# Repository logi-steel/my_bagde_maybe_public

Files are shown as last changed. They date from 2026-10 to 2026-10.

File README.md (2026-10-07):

# my_bagde_maybe_public
some ai slop mixed with my learning lol 

# E-ink badge you can reprogram from your phone
**Some ai slop mixed with my learning so pls be carefull.**
A tiny name badge: ESP32-C3 + 2.13" e-paper, **MicroPython**, everything on the screen is described
by one `config.json`. Long-press the button, scan the QR code on the badge, and edit the layout,
add pages, upload images/fonts or even **change the Python code from your phone's browser**. No
PC, no toolchain, no recompiling.

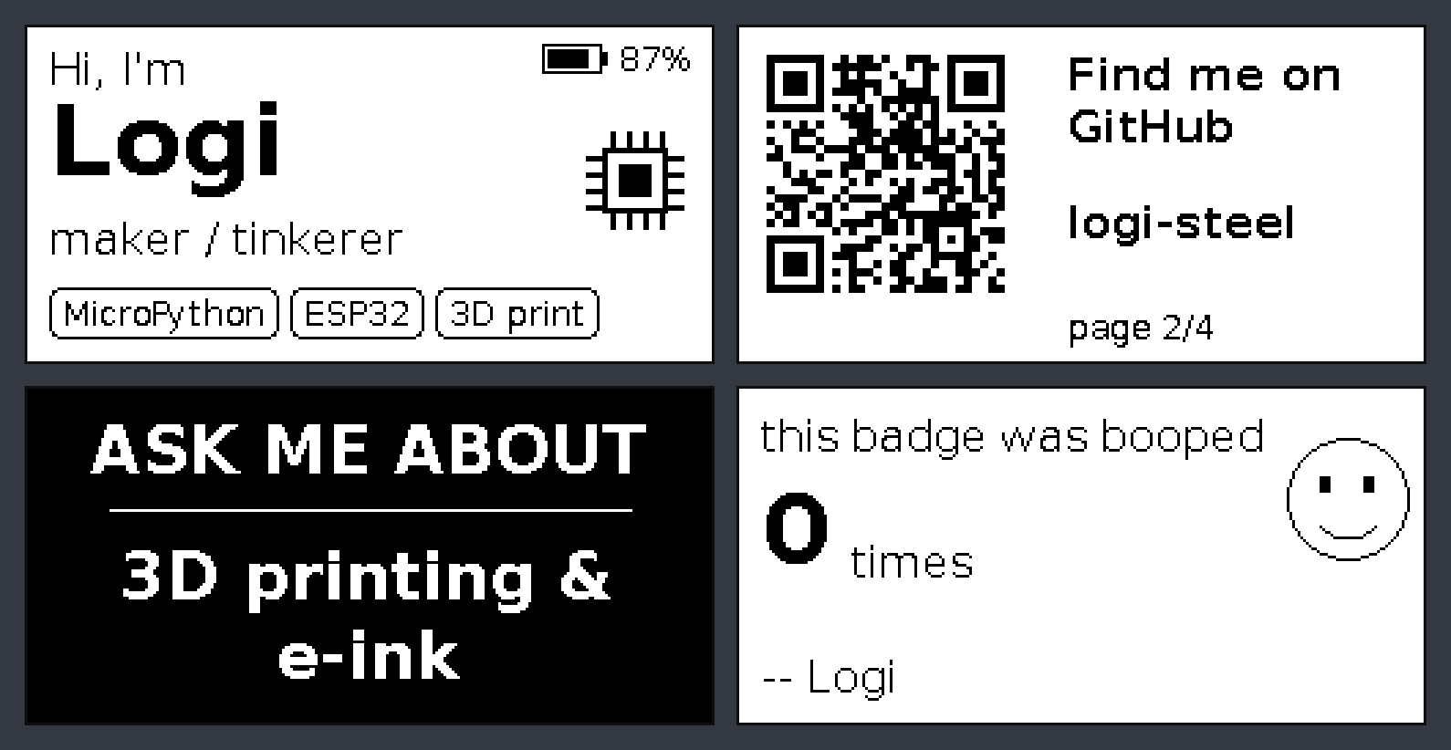
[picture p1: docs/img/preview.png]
preview of the four demo pages


*The picture above is rendered by the badge's own renderer running on a PC (`tools/preview.py`).*

* 250x122 e-paper, always readable, **zero power while showing a page** (deep sleep between presses)
* pages: text (Polish letters included), chips/tags, rectangles, lines, images (a full-screen picture from Canva & co,
  or pixel art typed as text), **QR codes** (generated on the
  device, so a vCard or link can be edited from the phone), battery gauge, and your own **Python plugins**
* Wi-Fi portal with live preview rendered *by the badge itself*, JSON editor, file manager, image
  converter (dithering in the browser), rollback buttons, captive-portal pop-up
* safe by design: configs are validated and `.py` files are compile-checked **before** they are written,
  the previous version is kept as `.bak`, a crashing widget draws a "!" instead of killing the page,
  and if a firmware upload breaks the startup the badge **rolls back to the `.bak` files by itself** (once,
  no ping-pong loops) and keeps the broken version as `.bak` so you can look at it
* 3D-printable case (OpenSCAD, parametric, interference-checked)

## Make your own graphics

> **Use this template to make your own badge graphics!** *(Dzięki temu szablonowi możesz robić własną grafikę!)*

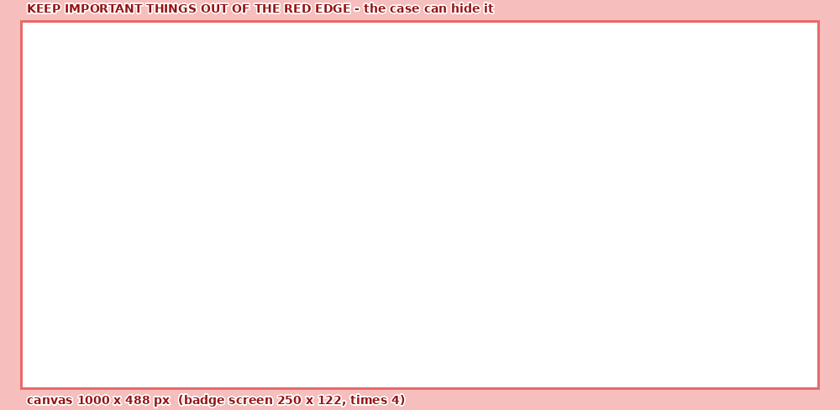
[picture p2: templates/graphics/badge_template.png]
the badge template: a red edge, everything else is yours


Take [`badge_template_overlay.png`](templates/graphics/badge_template_overlay.png) into Canva (or any editor), make a page of
**1000 x 488 px**, lay the overlay over it, draw whatever you like (your cat, any text, anywhere) and delete the overlay
before exporting. Then **Image -> Full screen -> Upload & add as a page** in the badge's portal. The only limits are the
screen size and the red edge the case may hide - [how it works, with an example](templates/graphics/README.md).

> **Read "What is verified and what is not" below before you buy parts or print the case.**
> I had no physical hardware: everything was tested against simulators/mocks and datasheets.

---

## Why MicroPython and not C++?

You all maybe asking whether C++ could update JSON *and code* on the fly. Honest answer:

| | C++ (Arduino/ESP-IDF) | MicroPython |
|---|---|---|
| JSON edited at runtime | easy (ArduinoJson + LittleFS + web server) | easy (`json` is built in) |
| **code changed at runtime** | only as a full firmware OTA: compile on a PC, upload a `.bin`. "Hot" code means embedding an interpreter - i.e. rebuilding MicroPython, worse | **native**: the `.py` files *are* the program, upload one over Wi-Fi and it runs next boot |
| speed | 10-100x faster | irrelevant here: drawing a page takes milliseconds, the e-paper refresh takes seconds |
| RAM/flash | tiny | ~100 KB heap is enough; the C3 has 400 KB SRAM and 4 MB flash |
| battery | slightly better | the badge sleeps at ~uA between presses either way |

C++ would only win for fast animations on a colour TFT. For an e-ink badge it is a bad trade.
**Verdict: MicroPython.** (And I would not choose a colour screen: it needs a backlight and lasts hours,
not weeks.)

---

## Hardware

| Part | What / why | Source of the numbers |
|---|---|---|
| **Seeed XIAO ESP32-C3** | 21 x 17.8 mm, USB-C, **LiPo charger on board**, 4 MB flash, external antenna included | [Seeed wiki](https://wiki.seeedstudio.com/XIAO_ESP32C3_Getting_Started/) |
| **2.13" e-paper, 250x122, B/W, SSD1680** | panel 29.2 x 59.2 x 1.05 mm, active area 23.71 x 48.55 mm, full refresh ~2-3 s, partial ~0.3-0.4 s | [Waveshare datasheet](https://files.waveshare.com/upload/e/e6/2.13inch_e-Paper_Datasheet.pdf), [Waveshare spec](https://www.waveshare.com/2.13inch-e-paper-hat.htm), [Good Display GDEY0213B74](https://eckstein-shop.de/GooDisplay-Marken-EN__213_1) |
| **display driver board** | a bare panel (24-pin 0.5 mm FPC) cannot be driven directly: the datasheet's reference circuit adds a MOSFET (GDR pin drives it), a 68 uH inductor, Schottky diodes and 1-4.7 uF capacitors. Buy a panel **with** its adapter board. SPI pins: VCC GND DIN CLK CS DC RST BUSY | [Waveshare pin table](https://www.waveshare.com/2.13inch-e-paper-hat.htm) |
| LiPo pouch cell, **>= 380 mAh**, max 6.5 x 21.5 x 42 mm | e.g. "602040" class (6.0 x 20 x 40, ~420 mAh). Seeed's wiki lists **380 mA** fast-charge, another source says 100 mA - measure before trusting it. At 380 mA a 250 mAh cell would charge at 1.5C, so take >= 380 mAh | [Seeed wiki](https://wiki.seeedstudio.com/XIAO_ESP32C3_Getting_Started/), [cell example](https://probots.co.in/3-7v-420mah-lipo-battery-602040-rechargeable-lithium-polymer-cell-with-protection-pcb.html) |
| tact switch 6x6x4.3 mm | the badge's only button | common part |
| 100 kohm resistor | **external pull-up on the button** (see below) | my design |
| optional: 2 x 470 kohm + 100 nF | battery % readout | my design |
| 4 x M2 x 8 countersunk screws | case | |

The Waveshare "e-Paper (Driver) HAT" boards are 65 x 30.2 mm Raspberry-Pi-HAT sized with a 40-pin header
([source](https://welectron.com/Waveshare-13512-e-Paper-Driver-HAT)); they do **not** fit the 34 x 21 mm driver
zone of the case without changing `drv` / `ci_y` in `case/badge_case.scad` (the asserts will tell you).

### Wiring (Seeed XIAO ESP32-C3 pin names -> GPIO from the [Seeed pin table](https://wiki.seeedstudio.com/XIAO_ESP32C3_Getting_Started/))

```
XIAO pin   GPIO   to
-------------------------------------------------
D8         8      e-paper CLK   (SPI SCK)
D10        10     e-paper DIN   (SPI MOSI)
D3         5      e-paper CS
D4         6      e-paper DC
D5         7      e-paper RST
D0         2      e-paper BUSY
3V3        -      e-paper VCC
GND        -      e-paper GND

D1         3      button -> GND,  AND 100k from D1 to 3V3   <- external pull-up
D2         4      (optional) midpoint of 2x470k from BAT+ to GND, 100 nF to GND, then set hardware.bat_adc = 4
BAT+/BAT-  -      LiPo (check the polarity printed on YOUR board before soldering!)
```

Why these pins (all checked in the MicroPython v1.29.0 source / Seeed docs, not guessed):

* **GPIO20/21 are not used**: the `ESP32_GENERIC_C3` build runs the REPL on UART0 there (`MICROPY_HW_ENABLE_UART_REPL`),
  an e-paper BUSY line wired to GPIO20 would type into the REPL.
* **GPIO9 is not used**: it is the BOOT strapping pin, a BUSY signal low at reset could put the chip in download mode.
* the button must be on **GPIO0-5**: only those can wake an ESP32-C3 from deep sleep (`machine.deepsleep` +
  `esp32.wake_on_gpio`). The internal pull-up is not guaranteed to survive deep sleep, hence the 100 kohm resistor.
* the config has a `hardware` section, so another wiring is a JSON edit, not a code change.

---

## Install

1. **Flash MicroPython** (v1.29.0 for `ESP32_GENERIC_C3`, [download page](https://micropython.org/download/ESP32_GENERIC_C3/)):

   ```sh
   pip install esptool mpremote
   esptool.py erase_flash
   esptool.py --baud 460800 write_flash 0 ESP32_GENERIC_C3-20260824-v1.29.0.bin
   ```
   If the board is not detected, hold **BOOT** while plugging in USB.
2. **Copy the firmware**: `python3 tools/deploy.py --reset`  (prints the `mpremote` command; `--dry-run` only prints).
3. The badge shows page 1 after a few seconds. Press the button for the next page.

Update later with `python3 tools/deploy.py --code-only` (keeps your `config.json`, plugins and images).

## Using the badge

| Action | Result |
|---|---|
| tap | next page (fast partial refresh; every 10th change is a full refresh to clear ghosting) |
| hold ~2 s | **Wi-Fi portal**: the e-paper shows a QR code that joins the badge's Wi-Fi |
| button in the portal | quit portal |

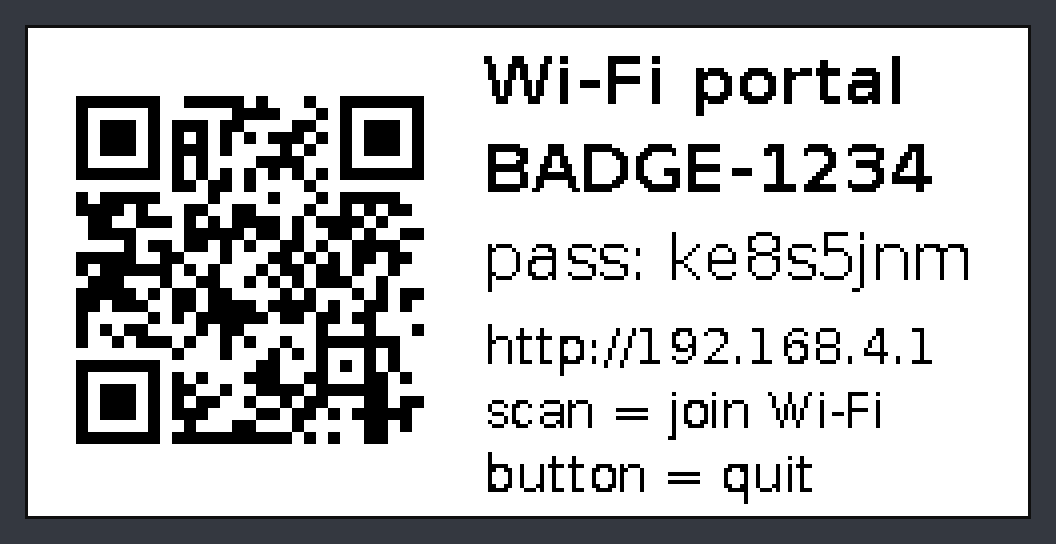
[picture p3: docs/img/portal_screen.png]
portal screen on the e-paper


1. Hold the button until the portal screen appears, scan the QR code (or type the SSID/password).
2. Open `http://192.168.4.1` (most phones pop it up automatically; a catch-all DNS makes that work).
3. **Preview** tab: live preview rendered by the badge with your unsaved edits - **Show on badge** refreshes the e-paper.
4. **Config** tab: edit the JSON, **Save**. **Files** tab: edit `.py`/`.json`, upload fonts/images/plugins, undo.
5. **Image** tab: pick a picture, it is dithered in the browser; **Upload & add as a page** uploads it as a `.pbm`
   and puts it on a new page (**Full screen** sizes it to the whole display) - see [make your own graphics](templates/graphics/README.md).
6. The portal closes after 5 idle minutes or on a button press, then the badge reboots into the new config.

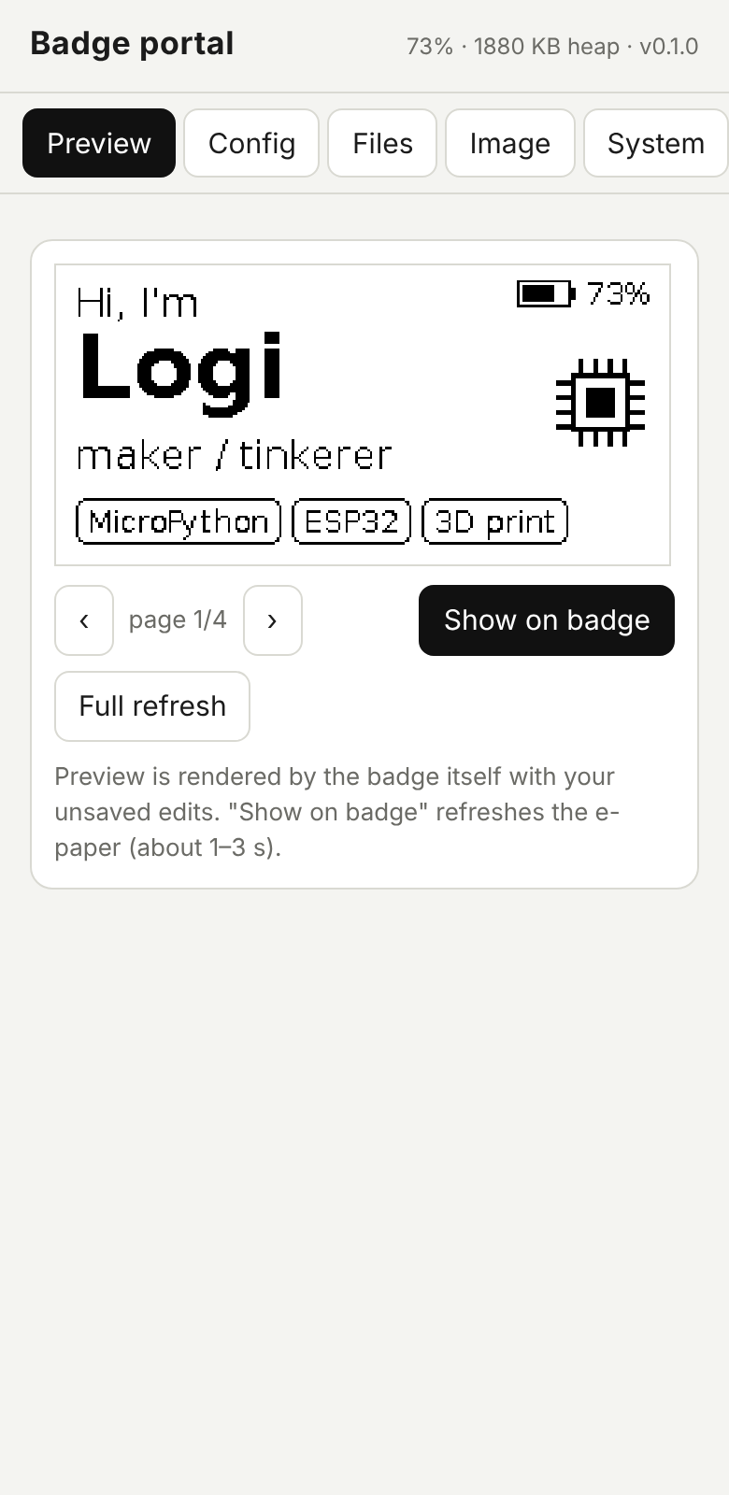
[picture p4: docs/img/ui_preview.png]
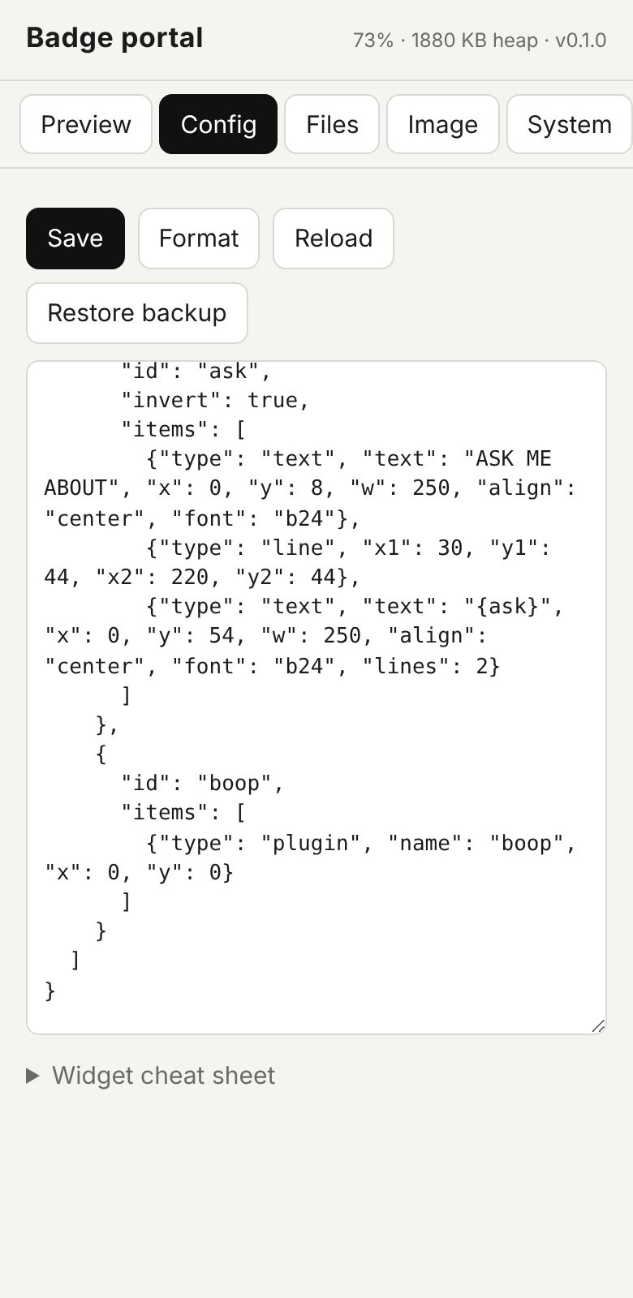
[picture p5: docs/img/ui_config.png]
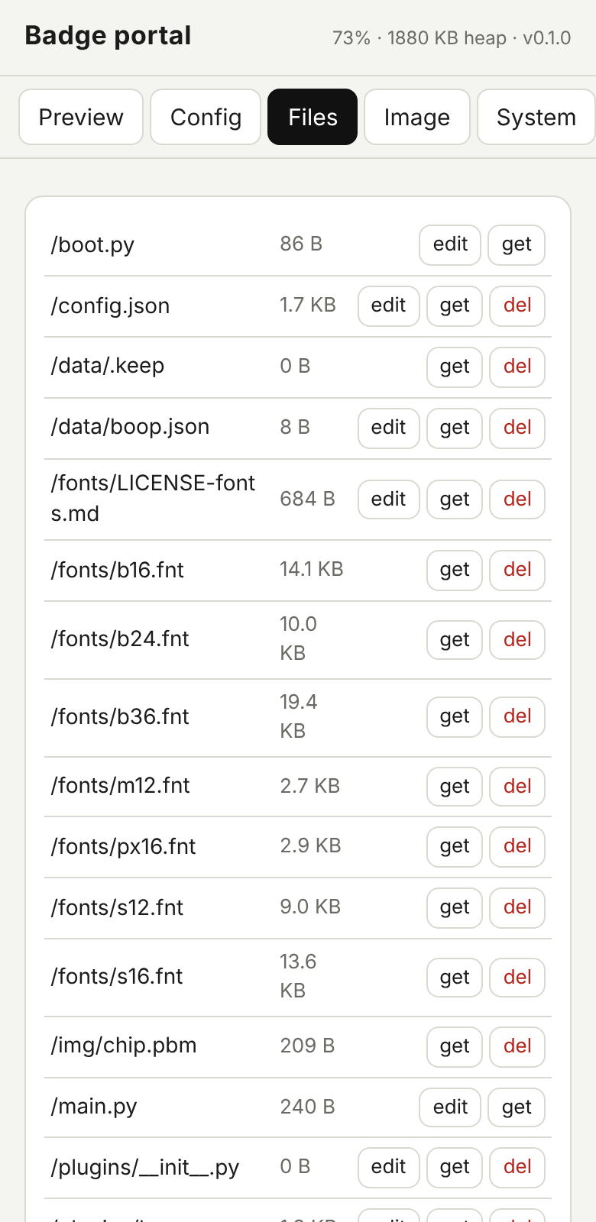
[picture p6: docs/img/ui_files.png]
  

Developing over USB: set `"sleep": "none"` in `config.json` and the badge stays awake (USB serial stays up) so
`mpremote` / `deploy.py` can reach it; set it back to `"deep"` for battery life.

Security: the Wi-Fi is WPA2 with a fresh random password on every portal start (shown on the e-paper). Whoever
joins can upload Python, so treat the password like a root password - that is the price of "change the code from
the phone". The portal only runs when you ask for it.

### config.json in 60 seconds

```jsonc
{
  "device": { "rotation": 0, "sleep": "deep", "full_refresh_every": 10, "auto_rotate_min": 0, "long_press_ms": 1200 },
  "vars":   { "name": "Logi", "role": "maker" },          // used as {name}, {role} in any text
  "pages": [
    { "items": [
        { "type": "text",  "text": "Hi, I'm", "x": 8, "y": 6,  "font": "s16" },
        { "type": "text",  "text": "{name}",  "x": 8, "y": 20, "font": "b36" },
        { "type": "chips", "items": ["MicroPython", "ESP32"], "x": 8, "y": 95, "font": "s12" },
        { "type": "qr",    "data": "https://github.com/logi-steel", "x": 140, "y": 4, "size": 110 },
        { "type": "battery", "x": 188, "y": 6 }
    ] },
    { "invert": true, "items": [ { "type": "text", "text": "ASK ME ABOUT", "x": 0, "y": 40, "w": 250, "align": "center", "font": "b24" } ] }
  ]
}
```

| widget | fields |
|---|---|
| `text` | `text x y [w align=left\|center\|right wrap lines gap font ink]`; `{vars}`, `{battery}`, `{page}`, `{pages}` |
| `rect` / `circle` / `line` | `x y w h [r fill ink]` / `x y r [fill]` / `x1 y1 x2 y2 [thickness]` |
| `image` | `src x y [scale invert opaque ink]` - 1-bit PBM from `tools/img2pbm.py` or the Image tab; `scale` enlarges by whole pixels, `opaque` paints the paper too |
| `art` | `rows[] (or data "..\|..") x y [scale on invert opaque ink]` - pixel art typed as text: `#` = ink, `.` = nothing (`tools/pixelart.py` converts to/from PBM and images) |
| `qr` | `data x y [size \| scale, ecc=L\|M\|Q\|H, border]` - up to 271 bytes at ECC L |
| `chips` | `items[] x y [w font padx pady gap r fill]` |
| `battery` | `x y [text]` (needs the divider on GPIO4 and `"hardware": {"bat_adc": 4}`; draws nothing otherwise) |
| `plugin` | `name x y ...your own keys` -> runs `plugins/<name>.py` |

Fonts: `s12 s16 b16 b24 b36 m12 px16` (DejaVu + Unifont, with Polish letters), `8x8` / `8x8x2` built in. Add your own with
`python3 tools/make_font.py --ttf X.ttf --size 20 --out firmware/fonts/x20.fnt` and upload it.

`rotation`: **0** = landscape with the FPC edge on the left, **180** = flipped, **90/270** = portrait. If the picture is
upside down, change 0 <-> 180 (I could not verify the orientation without a panel).

### Plugins = code you can change from the phone

`plugins/boop.py` is a working example (a persistent "booped N times" counter). A plugin is a function:

```python
def draw(c, item, ctx):      # c: Canvas, item: its JSON object, ctx: fonts/vars/page info
    ctx.font("b24").draw(c, ctx.fmt("Hi {name}"), item.get("x", 0), item.get("y", 0))
    c.rect(0, 0, c.w, 2, 0, True)
```

Upload it in the **Files** tab (or edit it there), add `{"type": "plugin", "name": "yourfile"}` to a page and watch the
preview change. Uploads are compile-checked first; **undo** swaps the old version back.

### Preview without hardware

```sh
sudo apt install micropython python3-pil     # or any MicroPython unix port + Pillow
python3 tools/preview.py                      # firmware/config.json -> docs/img/preview.png
python3 tools/preview.py my.json out.png --rotation 90
```

---

## Power

Numbers from the datasheets, **not measured by me**: XIAO ESP32-C3 deep sleep 44 uA (Seeed), e-paper standby < 0.01 uA
(Waveshare), refresh ~26 mW for a second or two, Wi-Fi ~75 mA but only while the portal is open. The e-paper keeps
the image without power, so a badge that is flipped a few times a day should run for months on a 400 mAh cell
(the optional battery divider with 2x470k adds ~4 uA, a battery self-discharge will matter more).

## 3D-printed case

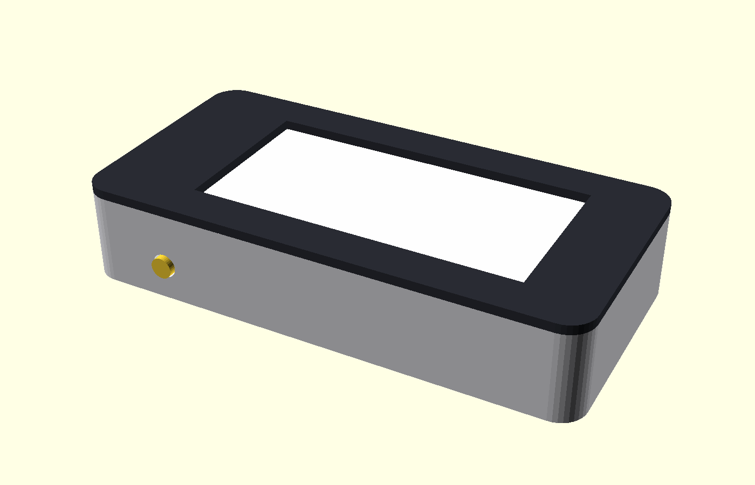
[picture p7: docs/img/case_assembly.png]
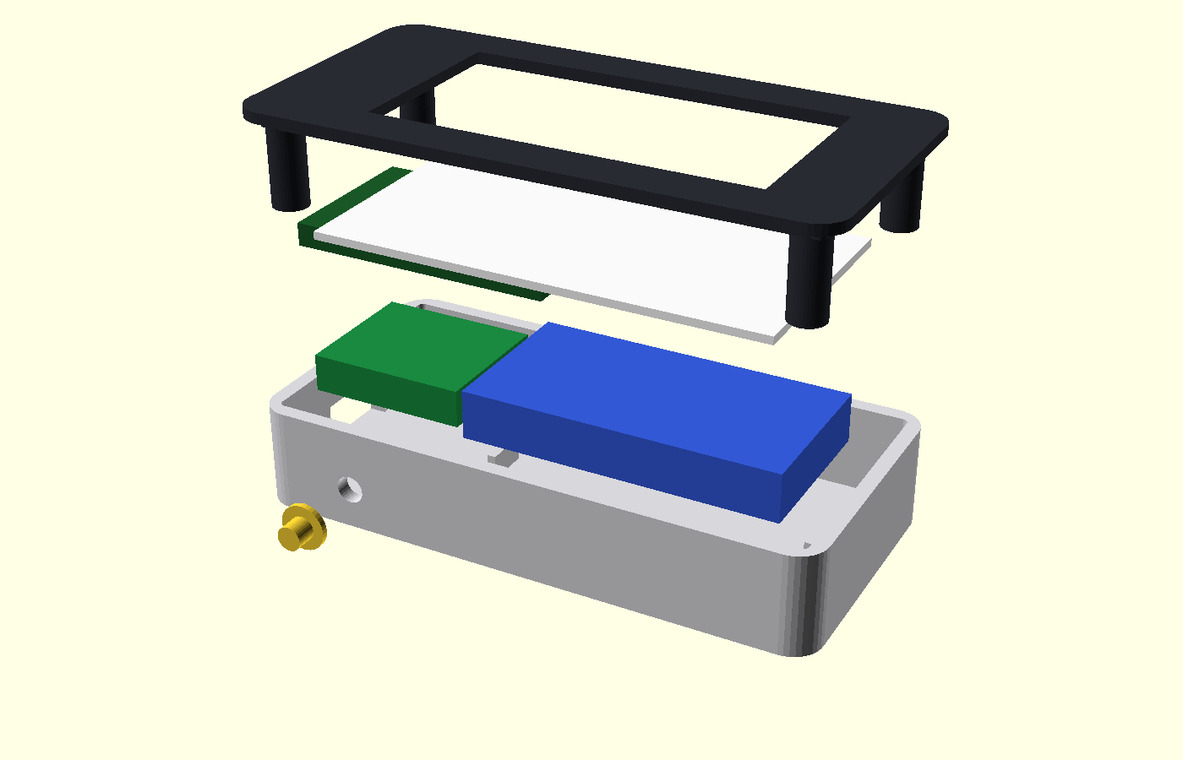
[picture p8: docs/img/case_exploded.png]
 
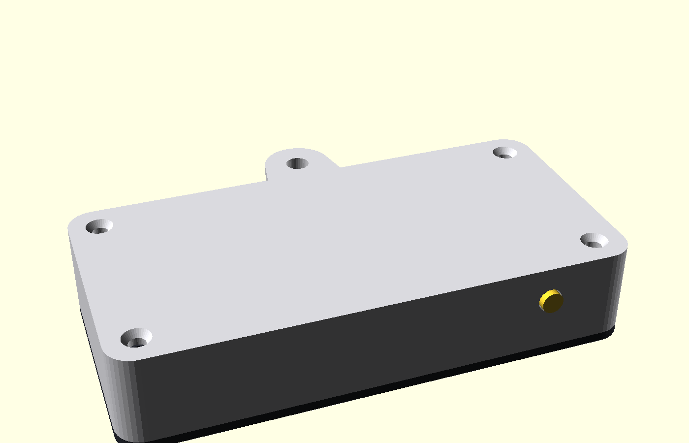
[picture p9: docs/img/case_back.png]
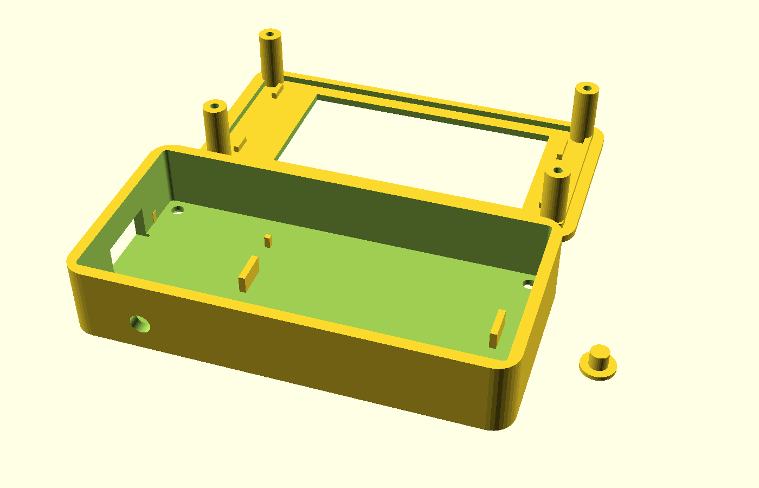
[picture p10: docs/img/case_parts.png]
 

Ready STLs are in [`case/stl`](case/stl) (`shell`, `bezel`, `cap`, `fit_test`, `gauge`); everything is parametric in
[`case/badge_case.scad`](case/badge_case.scad). 75 x 37 x 14.85 mm (+ a lug on the top edge for a lanyard).

* two parts closed with **4 x M2 x 8 countersunk screws from the back** (nothing on the front), the front plate has a
  lip that centres it, panel stops and four screw columns
* USB-C opening in the left wall (charging and flashing without opening the badge), button on the bottom edge,
  lanyard lug on the top edge, optional 6 x 2 mm magnet pockets (`magnets = true`), `fpc_left` for the other orientation
* print in PLA/PETG, 0.2 mm layers, 3 walls, **no supports**: `shell` open side up, `bezel` window side **down**, `cap` standing up

**Print the two small test pieces first** (a few minutes each):

* `fit_test.stl` - the front plate with the window and lip: drop your panel in, does the active area line up with the window?
* `gauge.stl` - slots for your XIAO, battery, driver board and switch: do they really fit?

Then adjust the parameters at the top of the `.scad` file (`aa_far`, `drv`, `xiao`, `bat`, ...) and re-export.

Build order: wire everything (see above) -> battery and XIAO into the shell (USB-C towards the left wall opening) ->
driver board above them -> panel into the bezel (thin double-sided tape, FPC folded behind it) -> bezel on the shell
-> 4 screws -> press the cap into the bottom-edge hole before closing.

`python3 tools/check_case.py` rebuilds the STLs and verifies: OpenSCAD asserts, no overlap between the stand-ins for panel /
driver / XIAO / battery / switch and the printed parts (also for `fpc_left=false` and `magnets=true`), every STL is a closed
solid, and an oversized battery trips an assert.

---

## What is verified and what is not

**Verified from primary sources** (datasheets / source code, with links above):
panel outline, active area and pixel count; SPI pin names and 3.3 V operation; XIAO ESP32-C3 size, pin-to-GPIO table,
BOOT pin, USB-serial console, external antenna; MicroPython v1.29.0 facts the firmware relies on (AP config keys,
`wake_on_gpio` is implemented via `esp_deep_sleep_enable_gpio_wakeup`, `machine.wake_pins()`, `PIN_WAKE` = EXT0,
UART REPL on GPIO20/21, `RTC.memory` 2048 bytes, `ADC.read_uv`, C3 has only `SPI(1)`); the e-paper register sequences
(copied from Waveshare's driver).

**Tested on the host (all green, `tests/run.sh`)**:

| suite | what it proves |
|---|---|
| `display` | every one of the 30,500 logical pixels lands on the right native pixel of a simulated SSD1680 for all 4 rotations; full/partial/sleep/busy-timeout sequences |
| `qr` | the on-device QR encoder is **bit-identical** to `python-qrcode` for v1-v10 x L/M/Q/H x 8 masks, capacities match `segno`, codes decode with OpenCV |
| `layout` | JSON -> pixels, wrapping, alignment, widget error isolation, config validation, atomic save + backup + fallback |
| `app` | the whole wake -> render -> SPI -> sleep flow: power-on, tap, partial/full cadence, auto-rotate timer, long press, stuck button, missing panel, crash screen, dev mode |
| `power` | battery percentage curve and ADC path, button helpers |
| `recover` | a broken over-the-air update: automatic rollback, the broken file stays as `.bak`, no rollback loop when both versions are bad, an hour of sleep instead of a crash loop |
| `portal` | real HTTP + DNS against the firmware: config save/restore, validation, draft preview, plugin upload + hot reload + rollback, syntax-error rejection, path traversal, size limits, 6 parallel clients, idle/button quit - and the **join QR decoded from the simulated e-paper pixels equals the Wi-Fi credentials** |
| `tools` | img2pbm, make_font, deploy command, preview |
| `graphics` | `art` / `scale` / `opaque` / `invert` drawn pixel for pixel, PBM reader limits, bad input rejected without crashing the page |
| `pixelart` | `tools/pixelart.py` round trips (text <-> PBM <-> image) through the firmware's own reader and validator; PBM polarity checked against ImageMagick |
| `graphics_template` | the template PNGs: sizes, transparent inside, red edge all round, they are exactly what `tools/make_graphics_template.py` makes; the cat example converts to a valid 250x122 PBM |
| `portal_ui` | headless Chromium against the simulated badge: choose a picture -> Full screen -> Upload & add as a page; the page lands in the config once, the `.pbm` is 250x122, no JS errors (skipped when playwright/chromium is missing) |
| web UI | also driven by hand with headless Chromium earlier (found and fixed a real bug that way) |
| case | see above |

**NOT verified - no hardware, no way for me to check:**

1. **Real panel behaviour**: the driver follows Waveshare's sequences, but I could not run it. Partial refresh after
   deep sleep assumes the panel keeps its RAM in sleep mode 1 (datasheet says so). If you see garbage/ghosting set
   `"full_refresh_every": 1`.
2. **Orientation**: rotation 0 vs 180 can be flipped (the panel scan direction vs the case is not in the datasheet).
3. **XIAO charge current**: Seeed's wiki says 380 mA, another source 100 mA. Measure before charging a small cell.
4. **Window offset in the case**: `aa_far = 3.05` comes from the drawing of the *older* 2.13" panel generation (same
   outline). The SSD1680 version is expected to be mechanically identical, but print `fit_test.stl` first.
5. **Assumed sizes**: driver board 34 x 21 x 3 mm, XIAO thickness 5 mm (one source), XIAO PCB 1 mm, LiPo envelope.
6. **Timing on the C3**: host renders in 1-15 ms; the C3 is far slower but the e-paper refresh (seconds) dominates.
   Heap use on the C3 is not measured.
7. Host tests ran on MicroPython 1.22.1 (the apt build); the device runs 1.29.0. Differences were checked in the
   1.29.0 sources only where the firmware depends on them.

## Repository layout

```
firmware/   what goes on the badge (main.py, badge/ package, web/index.html, fonts/, img/, plugins/, config.json)
case/       badge_case.scad + stl/
templates/  graphics/: the template for your own graphics, how-to and a worked example
tools/      deploy.py  preview.py  make_font.py  img2pbm.py  pixelart.py  make_graphics_template.py  check_case.py
tests/      run.sh (host test runner), mocks/ (machine, esp32, network, SSD1680 simulator), test_*.py
docs/img/   pictures used in this README
```

Run all tests: `sudo apt install micropython openscad xvfb && pip install pillow numpy opencv-python-headless segno qrcode trimesh fonttools mpremote && tests/run.sh`
(add `playwright` + its chromium for the browser test; ImageMagick's `convert` for the PBM polarity check)
(the runner downloads the pure-Python part of MicroPython's `asyncio` for the unix port into `tests/.hostlib`).

## Credits and licences

Code: MPL-2.0 (see `LICENSE`). E-paper command sequences derive from Waveshare's
[e-Paper](https://github.com/waveshareteam/e-Paper) driver (MIT-style licence). Fonts: see
[`firmware/fonts/LICENSE-fonts.md`](firmware/fonts/LICENSE-fonts.md) (DejaVu, GNU Unifont).

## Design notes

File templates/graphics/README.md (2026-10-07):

# Make your own badge graphics

> ## Use this template to make your own badge graphics!
> *(Dzięki temu szablonowi możesz robić własną grafikę!)*

the template: a red edge, everything else is yours

The whole screen is yours. The template only shows the two things you cannot change:

| | |
|---|---|
| **the size** | the badge screen is **250 x 122 px**. The template is that **x 4 = 1000 x 488 px**, big enough to work comfortably. |
| **the red edge** | a safety margin of 6 badge pixels (about 1.2 mm; 24 px here). In my case design the window is only 0.4 mm larger than the screen per side, and where the window really sits relative to the panel is not verified (see the main README), so the case may cover a bit of the edge. Do not put anything you need there - a photo may run into it, a name may not. |

Nothing else is prescribed: no zones, no grid, no fonts. A photo of your cat across the whole screen is fine, so is one
word in giant letters.

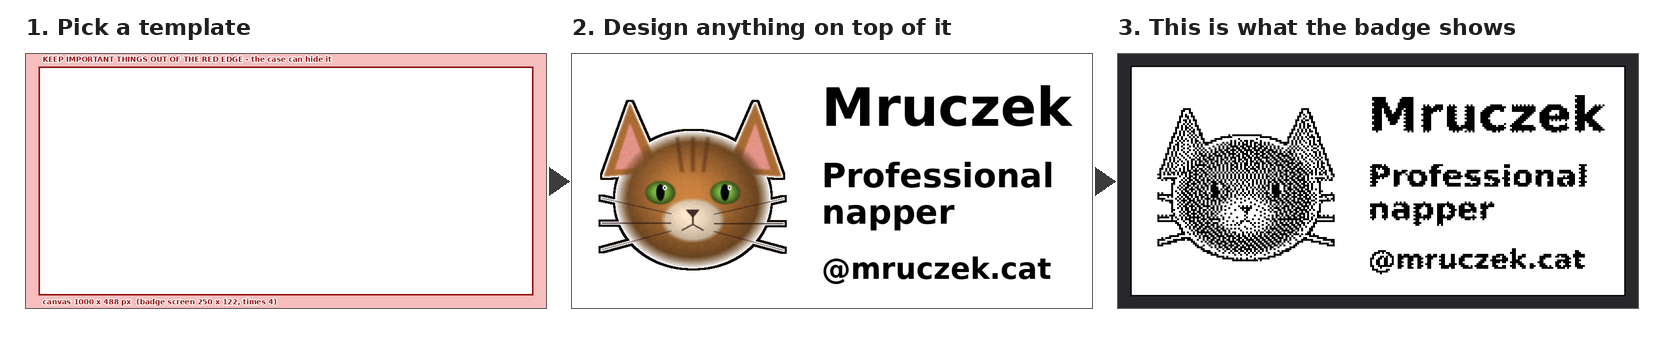
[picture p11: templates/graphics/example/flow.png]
template -> your design -> what the badge shows


*Example: `example/cat_design.png` is the middle picture; the right one is rendered by the badge's own renderer.
The cat is drawn by a script (`example/make_example.py`), a real photo works the same way.*

## How

1. **Take the template.** Use `badge_template_overlay.png` (transparent, only the red edge) - it lies on top of your
   design. `badge_template.png` is the same thing on white with a caption, for looking at.
2. **Open Canva** (or Photopea, Figma, GIMP, Paint.NET - anything that can make a page of an exact size and import a PNG):
   create a **custom size 1000 x 488 px**, upload the overlay and stretch it over the whole page.
3. **Design whatever you want** under the overlay: your cat, text, shapes. Keep the important parts out of the red edge.
4. **Delete (or hide) the overlay** and download the page as **PNG** (or JPG).
5. **On the badge:** hold the button ~2 s, scan the QR code to join its Wi-Fi, open `http://192.168.4.1`,
   tab **Image** -> choose your file -> **Full screen** -> **Upload & add as a page**. The page shows up in the
   preview; tap the button on the badge to flip to it.

I could not try Canva's menus - they change - so step 2 is the idea, not a click-by-click guide. The template is an
ordinary PNG, nothing Canva-specific. Step 5 was driven in a real browser against the simulated badge
(`tests/test_portal_ui.py`).

## What the screen can and cannot do

* **Only black and white.** No grey, no colour. Photos are turned into dots (*dithering*) - that is what the cat above
  looks like, and it is fine. Leave **dither** on for photos, switch it off for flat black-and-white art, logos and
  text (crisp edges, no dots).
* **A background that is not pure white turns into dots**, too: even a very light grey (248) becomes a sprinkle of dots.
  Make the backdrop *pure white* (`#FFFFFF`) and keep the photo's subject dark enough, with a clear outline.
* **Small text** gets hard to read. Look at the live preview and make it bigger if you squint.
* **Forgot the overlay?** With dither on it comes out as a faint dotted frame, with dither off it disappears. Re-export
  without it.
* **Portrait** (`"rotation": 90` in the config): use `badge_template_portrait*.png` (488 x 1000). **Full screen** reads the
  rotation from the badge and picks the width (122) for you.
* Other sizes work too: the portal scales to the chosen width and keeps the proportions (a picture that is
  not 250:122 simply leaves white space or is cut at the bottom).

## Beyond one picture

* A picture is just an **`image` widget** - `{"type": "image", "src": "img/photo.pbm", "x": 0, "y": 0}`. Other widgets
  (text with `{battery}`, a QR code, ...) can sit on top of it, and the pages you add are ordinary entries in
  `config.json`, so you can reorder, rename or delete them in the **Config** tab.
* `image` also takes `scale` (whole-number enlargement, crisp), `invert` and `opaque` - see the main README.
* **Draw with the keyboard**: the `art` widget and `tools/pixelart.py` turn text characters into pixels
  (`.` = nothing, `#` = ink) - good for icons, logos and pixel-art.

## From the command line (no portal)

```sh
python3 tools/img2pbm.py my_design.png cat.pbm --width 250               # dithered, for photos
python3 tools/img2pbm.py my_design.png cat.pbm --width 250 --threshold   # hard black/white
```

Upload `cat.pbm` to `img/` on the badge (portal **Files** tab, or over USB with `mpremote fs cp`) and add the `image`
widget above to a page.

## Files

| file | what |
|---|---|
| `badge_template_overlay.png` | **the one you lay over your design** (1000 x 488, transparent) |
| `badge_template.png` | the same, on white, with a caption - for looking |
| `badge_template_1x.png` | 250 x 122, for editors that work in exact screen pixels |
| `*_portrait*.png` | the same three, 488 x 1000 / 122 x 250 |
| `example/` | the cat: `cat_design.png` (what you export), `cat.pbm` (what the badge gets), `cat_on_badge.png`, `flow.png`, and `make_example.py` |

Regenerate the template with `python3 tools/make_graphics_template.py` (needs Pillow). The tests check that the PNGs
here are exactly what that script makes (`tests/test_graphics_template.py`).

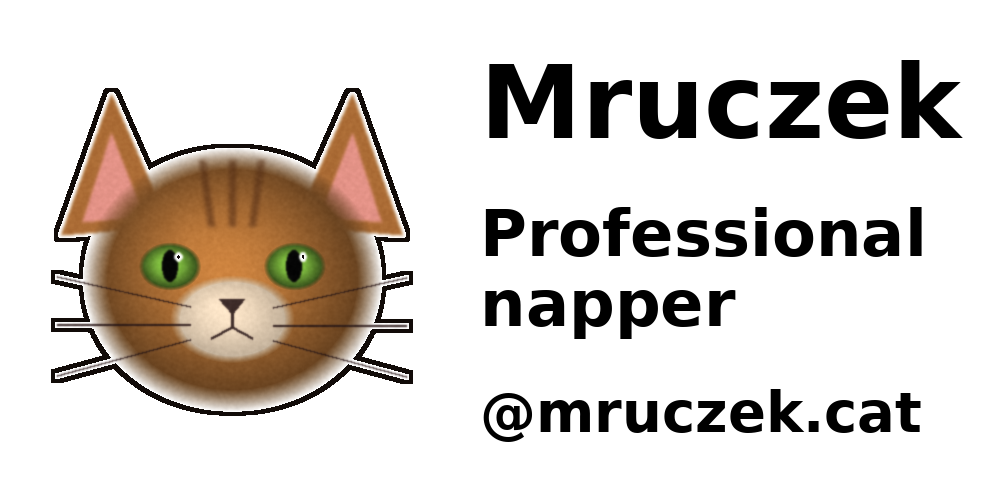
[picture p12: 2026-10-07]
templates/graphics/example/cat_design.png

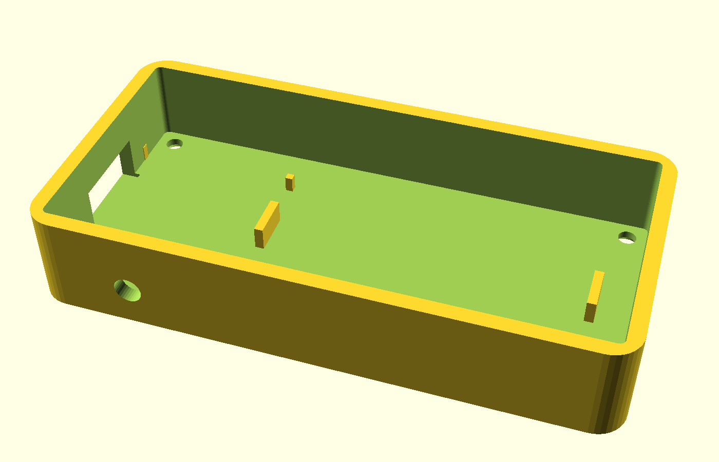
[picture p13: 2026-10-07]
docs/img/case_inside.png

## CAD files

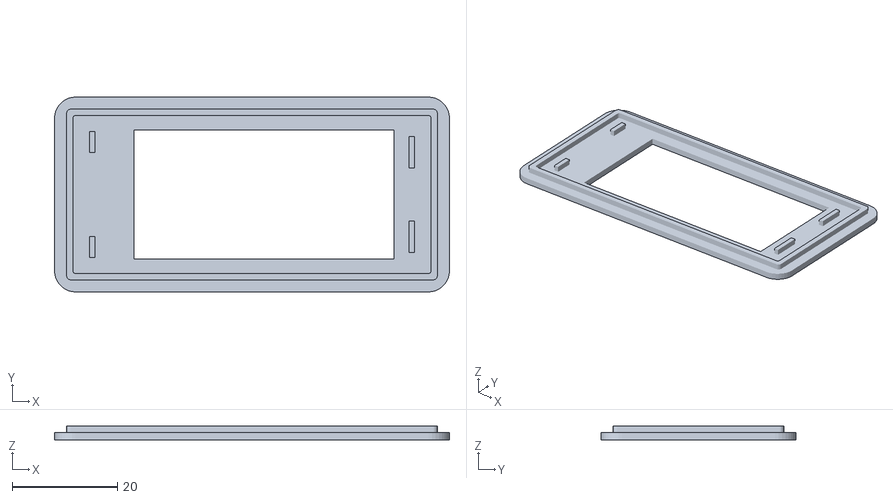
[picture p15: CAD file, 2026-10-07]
case/stl/fit_test.stl
75.0 x 37.0 x 2.65

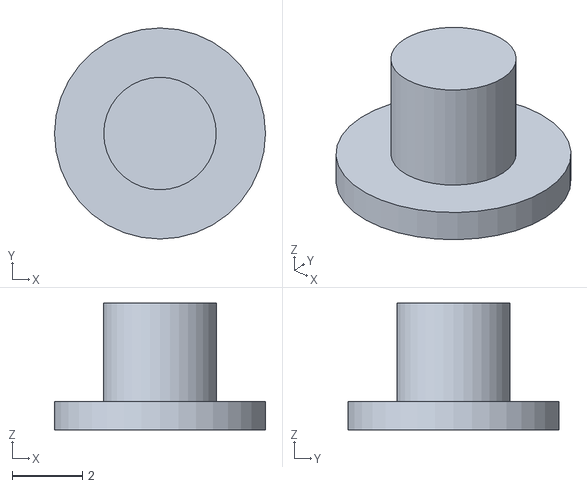
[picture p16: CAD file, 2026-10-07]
case/stl/cap.stl
6.00 x 6.00 x 3.60

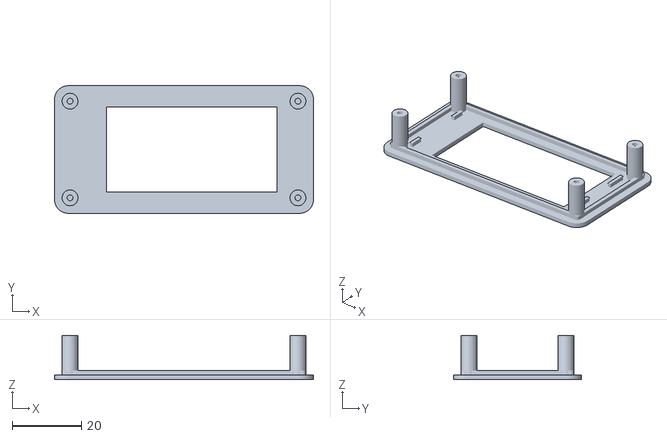
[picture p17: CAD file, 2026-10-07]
case/stl/bezel.stl
75.0 x 37.0 x 12.8

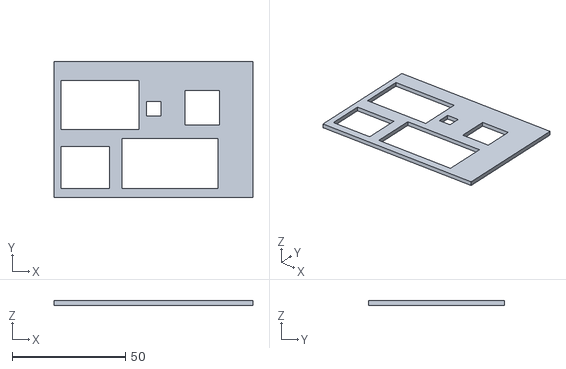
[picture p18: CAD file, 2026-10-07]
case/stl/gauge.stl
88.0 x 60.0 x 2.00

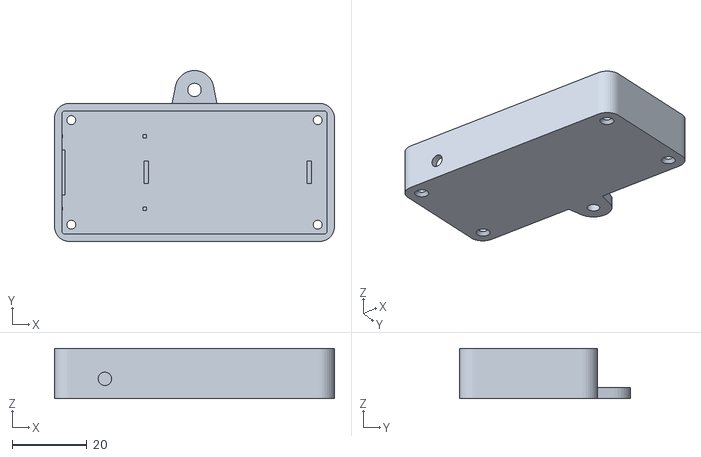
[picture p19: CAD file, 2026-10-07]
case/stl/shell.stl
75.0 x 45.8 x 13.4

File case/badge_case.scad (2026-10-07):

/*
  Mini e-ink badge case  -  parametric, OpenSCAD 2021.01+

  Two printed parts + a button cap, closed with 4x M2 screws from the BACK:
    bezel  front plate with the display window, a lip that centres it in the shell,
           panel stops and four screw columns that reach down to the back plate
    shell  back plate + walls: USB-C opening, button cage, lanyard lug, cradles
    cap    button plunger (prints standing up)

  Built around (README lists what is VERIFIED from datasheets and what is ASSUMED):
    2.13" e-paper panel 59.2 x 29.2 x 1.05, active area 48.55 x 23.71        (datasheet)
    Seeed XIAO ESP32-C3 21 x 17.8 (+ USB-C on a short edge)                  (Seeed wiki)
    LiPo pouch cell up to 6.5 x 21.5 x 42 ("602040" class)                   (nominal + margin)
    display driver board envelope 34 x 21 x 3.0                               (ASSUMPTION - measure)
    6x6 tact switch, 4.3 mm tall, lying on its side                           (common part)

  openscad -o shell.stl -D 'part="shell"' badge_case.scad
  part: assembly | exploded | bezel | shell | cap | fit_test | gauge | plate
        check_*  = interference tests, every one of them must come out EMPTY
*/

part = "assembly";
$fn = 36;

// ---------------------------------------------------------------- parts you buy (measure yours!)
panel_l = 59.2;  panel_w = 29.2;  panel_t = 1.05;     // 2.13" panel, landscape: length along X
aa_l = 48.55;    aa_w = 23.71;                         // active area
aa_far = 3.05;   // edge opposite the FPC -> first active pixel. Taken from the Waveshare drawing
                 // of the older 2.13" generation (same outline). VERIFY on your panel!
fpc_left = true; // FPC leaves the LEFT short edge (= firmware "rotation": 0); false = right

drv  = [34, 21, 3.0];     // display driver board envelope   (ASSUMPTION)
xiao = [21, 17.8, 5.0];   // XIAO ESP32-C3 incl. USB-C height (thickness from one source)
xiao_pcb_t = 1.0;         // XIAO PCB thickness (assumed; USB-C sits on top of it)
usb_h = 3.3;              // USB-C receptacle height
bat  = [42, 21.5, 6.5];   // LiPo envelope incl. protection board and wrap
sw   = [6.0, 6.0, 4.3];   // tact switch: width, height (lying on its side), length incl. plunger

// ---------------------------------------------------------------- design choices
wall = 2.0;  back_t = 2.0;  front_t = 1.4;
clr = 0.25;                 // panel clearance per side
lip_t = 1.2;  fit = 0.30;   // lip ring thickness, lip <-> cavity clearance per side
win_pad = 0.4;              // window is larger than the active area by this much per side
cr = 4.0;  cr_in = 0.8;     // outer / cavity corner radius
col_d = 4.6;  col_off = 2.5;   // screw columns: diameter, distance from the cavity walls
pilot_d = 1.7;  pilot_l = 9;   // M2 thread-forming screw pilot hole
scr_clear = 2.4;  scr_head = 4.0;
usb_w = 12.0;  usb_oh = 6.5;   // USB-C opening (clears the cable overmould)
btn_x = -24;                   // button on the bottom edge, above the narrow XIAO
btn_hole = 3.6;
cap_d = 3.2;  cap_flange_d = 6.0;  cap_flange_t = 0.8;
lug_r = 5.2;
magnets = false;               // optional 6x2 mm magnet pockets on the back
magnet_d = 6.2;  magnet_t = 2.2;

// ---------------------------------------------------------------- derived
bat_zone = bat[2] + 0.4;
drv_zone = drv[2] + 0.3;
pocket_d = panel_t + 0.2;
bay_h    = bat_zone + drv_zone + pocket_d;   // cavity depth below the shell rim
back_th  = magnets ? back_t + 1.0 : back_t;
z_floor  = back_th;
z_top    = z_floor + bay_h;                  // shell rim
H        = z_top + front_t;                  // total thickness

ci_x = 71;   ci_y = 33;                      // cavity inner size
ox = ci_x + 2 * wall;   oy = ci_y + 2 * wall;

fpc_sign = fpc_left ? -1 : 1;
aa_cx = -fpc_sign * (panel_l / 2 - aa_far - aa_l / 2);   // window centre vs panel centre

xiao_x = -ci_x / 2 + 0.4 + xiao[0] / 2;                    // XIAO at the left end (USB-C faces left)
bat_x  = -ci_x / 2 + 0.4 + xiao[0] + 2.0 + bat[0] / 2;
drv_x  = fpc_sign * (ci_x / 2 - 0.5 - drv[0] / 2);
col_x = ci_x / 2 - col_off;   col_y = ci_y / 2 - col_off;
usb_z = z_floor + xiao_pcb_t + usb_h / 2;                  // USB-C axis height
btn_z = z_floor + sw[1] / 2 + 0.3;
btn_pocket = cap_flange_t + 0.2 + sw[2] + 0.3;             // pocket length from the wall inward

// ---------------------------------------------------------------- sanity checks
assert(col_x - col_d / 2 >= panel_l / 2 + clr + 0.2, "screw columns collide with the panel ends - grow ci_x");
assert(col_y - col_d / 2 >= max(bat[1], drv[1], xiao[1]) / 2 + 0.3, "screw columns collide with battery/driver - grow ci_y");
assert(bat_x + bat[0] / 2 <= ci_x / 2 - 0.3, "battery + XIAO do not fit along X - grow ci_x");
assert(ci_y - 2 * fit - 2 * lip_t >= panel_w + 2 * clr - 0.5, "panel does not fit inside the lip ring");
assert(ci_y / 2 - btn_pocket - 0.8 >= bat[1] / 2 + 0.3 || btn_x < bat_x - bat[0] / 2 - 6, "button cage hits the battery");

// ---------------------------------------------------------------- helpers
module rbox(x, y, h, r) {
    hull() for (sx = [-1, 1], sy = [-1, 1])
        translate([sx * (x / 2 - r), sy * (y / 2 - r), 0]) cylinder(r = r, h = h);
}
module col_positions() {
    for (sx = [-1, 1], sy = [-1, 1]) translate([sx * col_x, sy * col_y, 0]) children();
}

// ---------------------------------------------------------------- the printed parts
module shell() {
    difference() {
        union() {
            rbox(ox, oy, z_top, cr);
            // lanyard lug on the top edge (badge hangs horizontally)
            hull() {
                translate([-6, oy / 2 - 2, 0]) cube([12, 2, 3]);
                translate([0, oy / 2 + lug_r - 1.6, 0]) cylinder(r = lug_r, h = 3);
            }
            // button cage block on the bottom edge, below the driver board layer
            translate([btn_x - (sw[0] + 3) / 2, -ci_y / 2 - 1, z_floor - 0.01])
                cube([sw[0] + 3, 1 + btn_pocket + 0.8, bat_zone]);
        }
        translate([0, 0, z_floor]) rbox(ci_x, ci_y, z_top, cr_in);                 // cavity
        // USB-C opening, axis aligned with the receptacle
        translate([-ci_x / 2 - wall - 1, -usb_w / 2, usb_z - usb_oh / 2]) cube([wall + 1.8, usb_w, usb_oh]);
        // button: pocket for flange + switch, hole for the plunger
        translate([btn_x - (sw[0] + 0.3) / 2, -ci_y / 2 - 0.01, btn_z - (sw[1] + 0.3) / 2])
            cube([sw[0] + 0.3, btn_pocket, sw[1] + 0.3]);
        translate([btn_x, -oy / 2 - 1, btn_z]) rotate([-90, 0, 0]) cylinder(d = btn_hole, h = wall + 2);
        col_positions() {                                                          // screws from the back
            translate([0, 0, -0.01]) cylinder(d = scr_clear, h = back_th + 0.02);
            translate([0, 0, -0.01]) cylinder(d1 = scr_head, d2 = scr_clear, h = 1.0);
        }
        translate([0, oy / 2 + lug_r - 1.6, -0.01]) cylinder(d = 3.6, h = 3.1);   // lug hole
        if (magnets) for (sx = [-1, 1]) translate([sx * 14, 0, -0.01]) cylinder(d = magnet_d, h = magnet_t);
    }
    // XIAO corner stops (low, parts drop in from above) and battery end stops
    for (sx = [-1, 1], sy = [-1, 1])
        translate([xiao_x + sx * (xiao[0] / 2 + 0.8) - 0.5, sy * (xiao[1] / 2 + 0.8) - 0.5, z_floor - 0.01])
            cube([1, 1, 2.2]);
    for (sx = [-1, 1])
        translate([bat_x + sx * (bat[0] / 2 + 0.8) - 0.6, -3, z_floor - 0.01]) cube([1.2, 6, 3.2]);
}

module panel_stops() {   // keep the panel from sliding along X; stay clear of the FPC tail
    far = -fpc_sign * (panel_l / 2 + clr + 0.5);
    near = fpc_sign * (panel_l / 2 + clr + 0.5);
    for (sy = [-1, 1]) {
        translate([far - 0.5, sy * 8 - 3, z_top - pocket_d]) cube([1, 6, pocket_d + 0.01]);
        translate([near - 0.5, sy * 10 - 2, z_top - pocket_d]) cube([1, 4, pocket_d + 0.01]);
    }
}
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

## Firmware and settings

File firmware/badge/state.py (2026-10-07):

"""Tiny persistent state kept in RTC memory (survives deep sleep, lost on power-off)."""
import struct
import machine

_FMT = "<BBBBBH"
_MAGIC = 0xB7


class State:
    def __init__(self):
        self.page = 0
        self.partials = 0     # partial refreshes since the last full one
        self.panel_ok = False  # panel holds an image we can partially refresh on top of
        self.crashes = 0
        self.battery = 0      # last measured percent (0 = unknown)

    def load(self):
        try:
            raw = machine.RTC().memory()
            m, page, partials, flags, crashes, bat = struct.unpack(_FMT, raw[:struct.calcsize(_FMT)])
            if m == _MAGIC:
                self.page, self.partials = page, partials
                self.panel_ok = bool(flags & 1)
                self.crashes, self.battery = crashes, bat
        except Exception:
            pass
        return self

    def save(self):
        try:
            machine.RTC().memory(struct.pack(_FMT, _MAGIC, self.page & 255, self.partials & 255,
                                             1 if self.panel_ok else 0, self.crashes & 255,
                                             self.battery & 0xFFFF))
        except Exception:
            pass

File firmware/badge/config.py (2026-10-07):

"""Loading, validating and saving /config.json (the whole badge is described by it)."""
import json
from . import util

CONFIG = "/config.json"
BACKUP = "/config.json.bak"

WIDGETS = ("text", "rect", "line", "circle", "image", "art", "qr", "chips", "battery", "plugin")

DEFAULTS = {
    "version": 1,
    "device": {
        "rotation": 0,            # 0/180 landscape, 90/270 portrait; flip 0<->180 if upside down
        "sleep": "deep",          # "deep" (battery) or "none" (stay awake, for USB development)
        "full_refresh_every": 10,  # every Nth page change is a full (flashing) refresh
        "auto_rotate_min": 0,     # 0 = only change pages on button press
        "long_press_ms": 1200,    # hold the button this long to open the config portal
        "portal": {"timeout_s": 300, "ssid": "", "password": "", "port": 80},
    },
    "hardware": {                 # GPIO numbers, defaults = Seeed XIAO ESP32-C3 wiring from README
        "spi_id": 1, "sck": 8, "mosi": 10, "miso": 9,
        "cs": 5, "dc": 6, "rst": 7, "busy": 2,
        "btn_next": 3, "btn_prev": None,
        "bat_adc": None,          # set to 4 after adding the 2x470k divider (floating pin = random %)
        "bat_divider": 2.0,
    },
    "vars": {},
    "pages": [],
}

ERROR_PAGE = {
    "items": [
        {"type": "text", "text": "config.json problem", "x": 4, "y": 4, "font": "b16"},
        {"type": "text", "text": "{error}", "x": 4, "y": 30, "w": 242, "font": "s12", "lines": 6},
        {"type": "text", "text": "Hold button 2s = Wi-Fi portal", "x": 4, "y": 104, "font": "s12"},
    ]
}


def _merge(base, over):
    out = {}
    for k in base:
        if k in over and isinstance(base[k], dict) and isinstance(over[k], dict):
            out[k] = _merge(base[k], over[k])
        elif k in over:
            out[k] = over[k]
        else:
            b = base[k]
            out[k] = dict(b) if isinstance(b, dict) else (list(b) if isinstance(b, list) else b)
    for k in over:
        if k not in base:
            out[k] = over[k]
    return out


def _is_num(v):
    return isinstance(v, (int, float)) and not isinstance(v, bool)


def validate(cfg):
    """Return (errors, warnings). Errors make a config unsafe to save."""
    errs, warns = [], []
    if not isinstance(cfg, dict):
        return ["top level must be a JSON object"], warns
    dev = cfg.get("device", {})
    if not isinstance(dev, dict):
        errs.append("device must be an object")
        dev = {}
    if dev.get("rotation", 0) not in (0, 90, 180, 270):
        errs.append("device.rotation must be 0, 90, 180 or 270")
    if dev.get("sleep", "deep") not in ("deep", "none"):
        errs.append('device.sleep must be "deep" or "none"')
    for k in ("full_refresh_every", "auto_rotate_min", "long_press_ms"):
        if k in dev and not _is_num(dev[k]):
            errs.append("device.%s must be a number" % k)
    hw = cfg.get("hardware", {})
    if not isinstance(hw, dict):
        errs.append("hardware must be an object")
        hw = {}
    for k, v in hw.items():
        if v is not None and not _is_num(v):
            errs.append("hardware.%s must be a number or null" % k)
    if dev.get("sleep", "deep") == "deep":
        for k in ("btn_next", "btn_prev"):
            if _is_num(hw.get(k)) and hw[k] > 5:
                warns.append("hardware.%s=%s: on ESP32-C3 only GPIO0-5 can wake from deep sleep" % (k, hw[k]))
    if not isinstance(cfg.get("vars", {}), dict):
        errs.append("vars must be an object")
    pages = cfg.get("pages", [])
    if not isinstance(pages, list):
        errs.append("pages must be a list")
        pages = []
    if not pages:
        warns.append("no pages defined")
    rot = dev.get("rotation", 0)
    w, h = (250, 122) if rot in (0, 180) else (122, 250)
    for pi, page in enumerate(pages):
        tag = "pages[%d]" % pi
        if not isinstance(page, dict) or not isinstance(page.get("items", []), list):
            errs.append(tag + " must be an object with an items list")
            continue
        for ii, it in enumerate(page.get("items", [])):
            t = "%s.items[%d]" % (tag, ii)
            if not isinstance(it, dict):
                errs.append(t + " must be an object")
                continue
            typ = it.get("type")
            if typ not in WIDGETS:
                errs.append("%s: unknown type %r (use %s)" % (t, typ, ", ".join(WIDGETS)))
                continue
            for k in ("x", "y", "w", "h", "r", "size", "scale", "lines", "x1", "y1", "x2", "y2", "gap"):
                if k in it and not _is_num(it[k]):
                    errs.append("%s.%s must be a number" % (t, k))
            if typ == "text" and "text" not in it:
                errs.append(t + ": text needs a \"text\" field")
            if typ == "text":
                f = it.get("font", "s16")
                if f != "8x8" and not util.exists("/fonts/%s.fnt" % f):
                    warns.append("%s: font %r not found in /fonts" % (t, f))
            if typ == "image":
                if not it.get("src"):
                    errs.append(t + ": image needs \"src\"")
                elif not util.exists("/" + it["src"].lstrip("/")):
                    warns.append("%s: image %r not found" % (t, it["src"]))
            if typ == "art":
                rows = it.get("rows")
                if rows is None and isinstance(it.get("data"), str):
                    rows = it["data"].split("|")
                if not isinstance(rows, list) or not all(isinstance(r, str) for r in rows):
                    errs.append(t + ': art needs "rows": a list of strings')
                else:
                    aw = max([len(r) for r in rows] or [0]) * max(1, int(it.get("scale", 1) or 1))
                    ah = len(rows) * max(1, int(it.get("scale", 1) or 1))
                    if aw > 1000 or ah > 1000:
                        errs.append("%s: art is too big (%dx%d px)" % (t, aw, ah))
                    elif _is_num(it.get("x", 0)) and _is_num(it.get("y", 0)) and (
                            it.get("x", 0) + aw > w or it.get("y", 0) + ah > h):
                        warns.append("%s: art (%dx%d px) reaches outside the %dx%d screen" % (t, aw, ah, w, h))
                if "on" in it and not isinstance(it["on"], str):
                    errs.append(t + ': "on" must be a string of ink characters')
            if typ == "qr" and not it.get("data"):
                errs.append(t + ": qr needs \"data\"")
            if typ == "plugin":
                name = it.get("name", "")
                if not name or not util.exists("/plugins/%s.py" % name):
                    warns.append("%s: plugin %r not found in /plugins" % (t, name))
            x = it.get("x", 0)
            y = it.get("y", 0)
            if _is_num(x) and _is_num(y) and (x >= w or y >= h or x < -w or y < -h):
                warns.append("%s: x/y outside the %dx%d screen" % (t, w, h))
    return errs, warns
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

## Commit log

2026-10-07 Add MicroPython e-ink badge firmware (ESP32-C3 + 2.13" SSD1680)
    Pages are described by one config.json (text, chips, shapes, images, QR codes,
    battery gauge, user plugins). The badge deep-sleeps between button presses; a
    long press opens a Wi-Fi portal (QR on the e-paper) with live preview, JSON and
    file editors, image converter and rollback buttons.
    - SSD1680 driver following Waveshare's V4 sequences, 4 rotations, partial refresh
    - bitmap fonts with Polish letters, on-device QR encoder (v1-10, ECC L/M/Q/H)
    - portal: asyncio HTTP + DNS catch-all, compile/validate before write, .bak undo
    - recover.py: one-shot automatic rollback of a broken OTA update
    - host tests on MicroPython (unix) with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
    [app.py, canvas.py, config.py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]
2026-10-07 Add parametric 3D-printable case (OpenSCAD) with verification
    Two printed parts closed with 4x M2 screws from the back, USB-C opening,
    button cage + cap, lanyard lug, fit-test coupon and component gauge.
    tools/check_case.py runs the SCAD asserts, interference checks (volume based),
    STL watertightness and the fpc_right / magnets variants.
    Claude-Session: https://claude.ai/code/session_01TmNM41kcNMUqkdc6VrDdS5
    [badge_case.scad, bezel.stl, cap.stl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]
2026-10-07 Document the badge: hardware, wiring, usage, case, and what is NOT verified
    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
2026-10-07 Disable battery sensing by default; test the battery and button helpers
    A floating ADC pin (no divider soldered) would show random battery percentages,
    so hardware.bat_adc is now null until the user wires the divider.
    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
2026-10-07 Add a template for making your own badge graphics
    A minimal template (screen size + the red edge the case may hide) to lay over a
    design in Canva & co, a how-to for non-technical users, and a worked example
    (a cat: template -> design -> what the badge shows).
    * templates/graphics: overlay / labelled / 1x template, landscape and portrait,
    generated by tools/make_graphics_template.py
    * portal Image tab: "Full screen" and "Upload & add as a page" (uploads the .pbm
    and adds or updates the page in config.json)
    * tests: template sizes, edge, reproducibility; the Image tab in headless
    Chromium (skipped when playwright is missing)
    * README: "Make your own graphics", art/image options, new tes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
    [test_graphics_template.py, test_portal_ui.py]
2026-10-07 Consistency pass: portal cheat sheet, red-edge wording, tests table
    * portal widget cheat sheet lists `art` and the new `image` options
    * the red edge is a safety margin, not "what the case hides": the case
    window is 0.4 mm larger than the active area per side, and its position is
    unverified (aa_far), so the docs no longer claim the case hides 1 mm
    * README tests table lists the `power` suite
    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
